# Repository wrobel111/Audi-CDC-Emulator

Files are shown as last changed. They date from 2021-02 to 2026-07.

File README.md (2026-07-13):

Audi CDC v1 1

# Audi CDC Emulator

Embedded CD changer emulator for Audi factory head units with Bluetooth audio streaming and hands-free phone functionality.

The project emulates an original Audi CD changer, allowing modern Bluetooth connectivity while preserving the original vehicle infotainment system. The hardware and firmware were designed to integrate seamlessly with factory radios without permanent vehicle modifications.

---

## Features

- Audi CD changer (CDC) protocol emulation
- Bluetooth audio streaming (A2DP)
- Hands-free phone functionality (HFP)
- Steering wheel (Rem-C line) and radio button support
- UART communication with Bluetooth module using AT commands
- Custom hardware designed for automotive applications
- AVR firmware written in C/C++

---

## Hardware

### Microcontroller

- ATmega328PB

### Bluetooth module

- BK3254

The Bluetooth module is controlled through UART using AT commands.

Supported AT commands:
https://github.com/tomaskovacik/BK3254/wiki/Supported-commands-and-event-send-from-module

---

## Hardware Design

The PCB was designed specifically for integration with the Audi factory audio system.

Main hardware components include:

- ATmega328PB microcontroller
- BK3254 Bluetooth module
- Audio amplifier
- Automotive power supply interface
- ISP programming connector
- UART service connector

Hardware design files are available in the `Hardware` directory.

---

## Firmware

The firmware is responsible for:

- emulating the Audi CD changer
- controlling the Bluetooth module
- handling button events
- switching between music playback and phone calls
- managing amplifier enable signals
- communication with the factory head unit

- ## Development History

### 24 May 2025

#### Added

- Support for BK3254 Bluetooth module
- Bluetooth music streaming
- Hands-free phone functionality

#### Changed

- Migrated timer implementation from Timer0 to Timer3 on ATmega328PB

---

## PCB Revision Notes (v1.1)

The following improvements are planned for the next PCB revision:

1. Add AUX detection using the switching contacts of the 3.5 mm jack connector.
2. Standardize the design to use the BK3254 Bluetooth module only.
3. Verify amplifier enable signal timing.
4. Replace the programming connector with a standard 6-pin ISP header.
5. Reorder the serial connector pinout:

   - +5 V
   - TX
   - RX
   - GND

6. Replace the audio amplifier with the SSM2211.
   - The SSM2211 uses an active LOW enable input, requiring inverted control logic.
7. Add series resistors and TVS protection diodes on the USB data lines.
8. Improve Digispark module pin placement for easier assembly and debugging.

CDC v1 1 with inprovements

---

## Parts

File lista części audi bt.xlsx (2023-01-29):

Zamówione | Part | Value | Device | Package | Library | Cena |  | Gdzie
100 szt. | C1 | 100n | C-EUC0805 | C0805 | rcl | 0,08050 |  | https://www.tme.eu/pl/details/cl21b104kbcnnnc/kondensatory-mlcc-smd-0805/samsung/
100 szt. | C2 | 22p | C-EUC0805 | C0805 | rcl | 0.06296 |  | https://www.tme.eu/pl/details/cc0805jrnpo9220/kondensatory-mlcc-smd-0805/yageo/cc0805jrnpo9bn220/
 | C3 | 22p | C-EUC0806 | C0806 | rcl | 0.06297
 | C4 | 100n | C-EUC0805 | C0805 | rcl | 0,08050
 | C5 | 100n | C-EUC0805 | C0805 | rcl | 0,08050
 | C6 | 100n | C-EUC0805 | C0805 | rcl | 0,08050
 | C7 | 100n | C-EUC0805 | C0805 | rcl | 0,08050
 | C8 | 100n | C-EUC0805 | C0805 | rcl | 0,08050
 | C9 | 100n | C-EUC0805 | C0805 | rcl | 0,08050
100 szt. | C10 | 1u | C-EUC0805 | C0805 | rcl | 0.100 |  | https://allegro.pl/oferta/kondensator-smd-0805-1uf-25v-10-szt-1337-10-6880076309
 | C11 | 1u | C-EUC0805 | C0805 | rcl | 0.100
 | C12 | 1u | C-EUC0805 | C0805 | rcl | 0.100
 | C13 | 1u | C-EUC0805 | C0805 | rcl | 0.100
 | C14 | 1u | C-EUC0805 | C0805 | rcl | 0.100
 | C15 | 1u | C-EUC0805 | C0805 | rcl | 0.100
 | C16 | 1u | C-EUC0805 | C0805 | rcl | 0.100
 | C17 | 1u | C-EUC0805 | C0805 | rcl | 0.100
 | C18 | 1u | C-EUC0805 | C0805 | rcl | 0.100
 | C19 | 1u | C-EUC0805 | C0805 | rcl | 0.100
 | C20 | 1u | C-EUC0805 | C0805 | rcl | 0.100
 | C21 | 100n | C-EUC0805 | C0805 | rcl | 0,08050
 | C22 | 100n | C-EUC0805 | C0805 | rcl | 0,08050
 | C23 | 1u | C-EUC0805 | C0805 | rcl | 0.100
 | C24 | 1u | C-EUC0805 | C0805 | rcl | 0.100
3 szt. | F1 | 1A | PTCFUSE-1206 | R1206 | adafruit | 2.06876 |  | https://www.tme.eu/pl/details/erbrg1r00v/bezpieczniki-smd-1206-szybkie/panasonic/
3 szt. | Q1 | 16 MHz | CRYSTALHC49S | HC49/S | crystal | 2,2983 |  | https://www.tme.eu/pl/details/16.00m-hc49-s/rezonatory-kwarcowe-tht/yic/
100 szt. | Q2 | BC847 | BC847ALT1SMD | SOT23 | transistor-npn | 0.029 |  | https://pl.aliexpress.com/item/33011051664.html?spm=a2g0s.9042311.0.0.27425c0fiXW19s
100 szt. | R1 | 10k | R-EU_R0805 | R0805 | rcl | 0.035 |  | https://pl.aliexpress.com/item/32969301387.html?spm=a2g0s.9042311.0.0.27425c0fiXW19s
100 szt. | R2 | 12k | R-EU_R0805 | R0805 | rcl | 0,06133 |  | https://www.tme.eu/pl/details/smd0805-12k-1%25/rezystory-smd-0805/royal-ohm/0805s8f1202t5e/
 | R3 | 12k | R-EU_R0805 | R0805 | rcl | 0,06133
 | R4 | 12k | R-EU_R0805 | R0805 | rcl | 0,06133
 | R5 | 12k | R-EU_R0805 | R0805 | rcl | 0,06133
 | R6 | 12k | R-EU_R0805 | R0805 | rcl | 0,06133
 | R7 | 12k | R-EU_R0805 | R0805 | rcl | 0,06133
 | R8 | 10k | R-EU_R0805 | R0805 | rcl | 0.035
 | R9 | 10k | R-EU_R0805 | R0805 | rcl | 0.035
 | R10 | 10k | R-EU_R0805 | R0805 | rcl | 0.035
 | R11 | 10k | R-EU_R0805 | R0805 | rcl | 0.035
 | R12 | 10k | R-EU_R0805 | R0805 | rcl | 0.035
100 szt. | R13 | 20k | R-EU_R0805 | R0805 | rcl | 0.06133 |  | https://www.tme.eu/pl/details/smd0805-20k-1%25/rezystory-smd-0805/royal-ohm/0805s8f2002t5e/
 | R14 | 20k | R-EU_R0805 | R0805 | rcl | 0.06133
100 szt. | R15 | 1,2k | R-EU_R0805 | R0805 | rcl | 0,06133 |  | https://www.tme.eu/pl/details/smd0805-1k2-1%25/rezystory-smd-0805/royal-ohm/0805s8f1201t5e/
 | R16 | 1,2k | R-EU_R0805 | R0805 | rcl | 0,06133
100 szt. | R17 | 0 | R-EU_R0805 | R0805 | rcl | 0.0213 |  | https://pl.aliexpress.com/item/32969301387.html?spm=a2g0s.9042311.0.0.27425c0fiXW19s
50 szt. | RESET |  | SWITCH_PUSHBUTTONSOFTTOUCHSMD_SJ | PUSHBUTTON_SMD_SJ | adafruit | 0.034 |  | https://pl.aliexpress.com/item/32652031692.html?spm=a2g0s.9042311.0.0.27425c0fEeSRBw
nie trzeba | S1 |  | pad do zlutowania
 | S2 |  | pad do zlutowania
 | S3 |  | pad do zlutowania
 | TP1 | TPB1,27 | TPB1,27 | B1,27 | testpad
 | TP2 | TPB1,27 | TPB1,27 | B1,27 | testpad
 | TP3 | TPB1,27 | TPB1,27 | B1,27 | testpad
 | TP4 | TPB1,27 | TPB1,27 | B1,27 | testpad
 | TP5 | TPB1,27 | TPB1,27 | B1,27 | testpad
 | TP6 | TPB1,27 | TPB1,27 | B1,27 | testpad
 | TP7 | TPB1,27 | TPB1,27 | B1,27 | testpad
 | TP8 | TPB1,27 | TPB1,27 | B1,27 | testpad
 | TP9 | TPB1,27 | TPB1,27 | B1,27 | testpad
10 szt. | TR1 | AUDIO_R | AUDIO_ISOLATION_TRANSFORMER_EI14 | EI14 | trafo EI14 | 1.150 |  | https://pl.aliexpress.com/item/32827431499.html?spm=a2g0s.9042311.0.0.50735c0friSdsd
 | TR2 | AUDIO_L | AUDIO_ISOLATION_TRANSFORMER_EI14 | EI14 | trafo EI14 | 1.150
 | TR3 | AUDIO_MIC | AUDIO_ISOLATION_TRANSFORMER_EI14 | EI14 | trafo EI14 | 1.150
2 szt. | U$7 | DIGISPARK | DIGISPARK | DIGISPARK | digispark | 5.720 |  | https://pl.aliexpress.com/item/32891293434.html
bk3254 3 szt. | U1 | BK3266_BOARD | BK3254 | 40PIN_BOARD | BK3266/BK3254 | 8.690 | Przesyłka | https://pl.aliexpress.com/item/32824037848.html
3 szt. | U2 | MEGA328P | MEGA8-AI | TQFP32-08 | atmel | 9.960 |  | https://www.tme.eu/pl/details/atmega328p-au/rodzina-avr-8-bit/microchip-atmel/
10 szt. | U3 | HT6872 | HT6872 | SO8 | HT6872 | 1.515 | przesylka | https://pl.aliexpress.com/item/32965069882.html?spm=a2g0s.9042311.0.0.27425c0fEeSRBw
 | U4 | HT6872 | HT6872 | SO8 | HT6872 | 2.515 | przesylka
 | U5 | HT6872 | HT6872 | SO8 | HT6872 | 3.515 | przesylka
10 szt. | U6 | AMS1117-3.3 | LM1117MPX-3.3 | SOT223 | lm1117 | 0.135 |  | https://pl.aliexpress.com/item/32834083645.html?spm=a2g0s.9042311.0.0.27425c0fEeSRBw
6 szt. | X1 | molex 4 pin | HEADER_POS4_43045-0401 | 43045-0400 | con-molex-micro-fit-3_0 | 2.000 |  | https://www.tme.eu/pl/details/mx-43045-0400/zlacza-sygnalowe-raster-3-00mm/molex/43045-0400/ | https://pl.aliexpress.com/item/32796641499.html
6 szt. | X2 | molex 16 pin | HEADER_POS16_43045-1600 | 43045-1600 | con-molex-micro-fit-3_0 | 3.260 |  | https://www.tme.eu/pl/details/mx-43045-1600/zlacza-sygnalowe-raster-3-00mm/molex/43045-1600/ | https://pl.aliexpress.com/item/4000786382682.html
 | X3 | goldpin 4 pin | PINHD-1X4 | 1X04 | pinhead
10 szt. | X4 | mini STEREOJACK | STEREOJACK | STX3100 | audio amplifier example | 0.232 |  | https://pl.aliexpress.com/item/33030284477.html?spm=a2g0s.9042311.0.0.27425c0fEeSRBw
10 szt. | X5 | USB-A-H | USB-A-H | USB-A-H | con-usb | 0.286 |  | https://pl.aliexpress.com/item/1005001705110068.html?spm=a2g0s.9042311.0.0.27425c0fEeSRBw
2 szt. |  | z97 | obudowa |  |  | 6.090 |  | https://www.tme.eu/pl/details/z-97/obudowy-z-panelem/kradex/z97/
5 szt. |  |  | pcb |  | 5,7 $ | 4.200 |  | jlcpcb
 |  |  |  |  | Suma | 55.479
 |  |  | mini iso niebieskie

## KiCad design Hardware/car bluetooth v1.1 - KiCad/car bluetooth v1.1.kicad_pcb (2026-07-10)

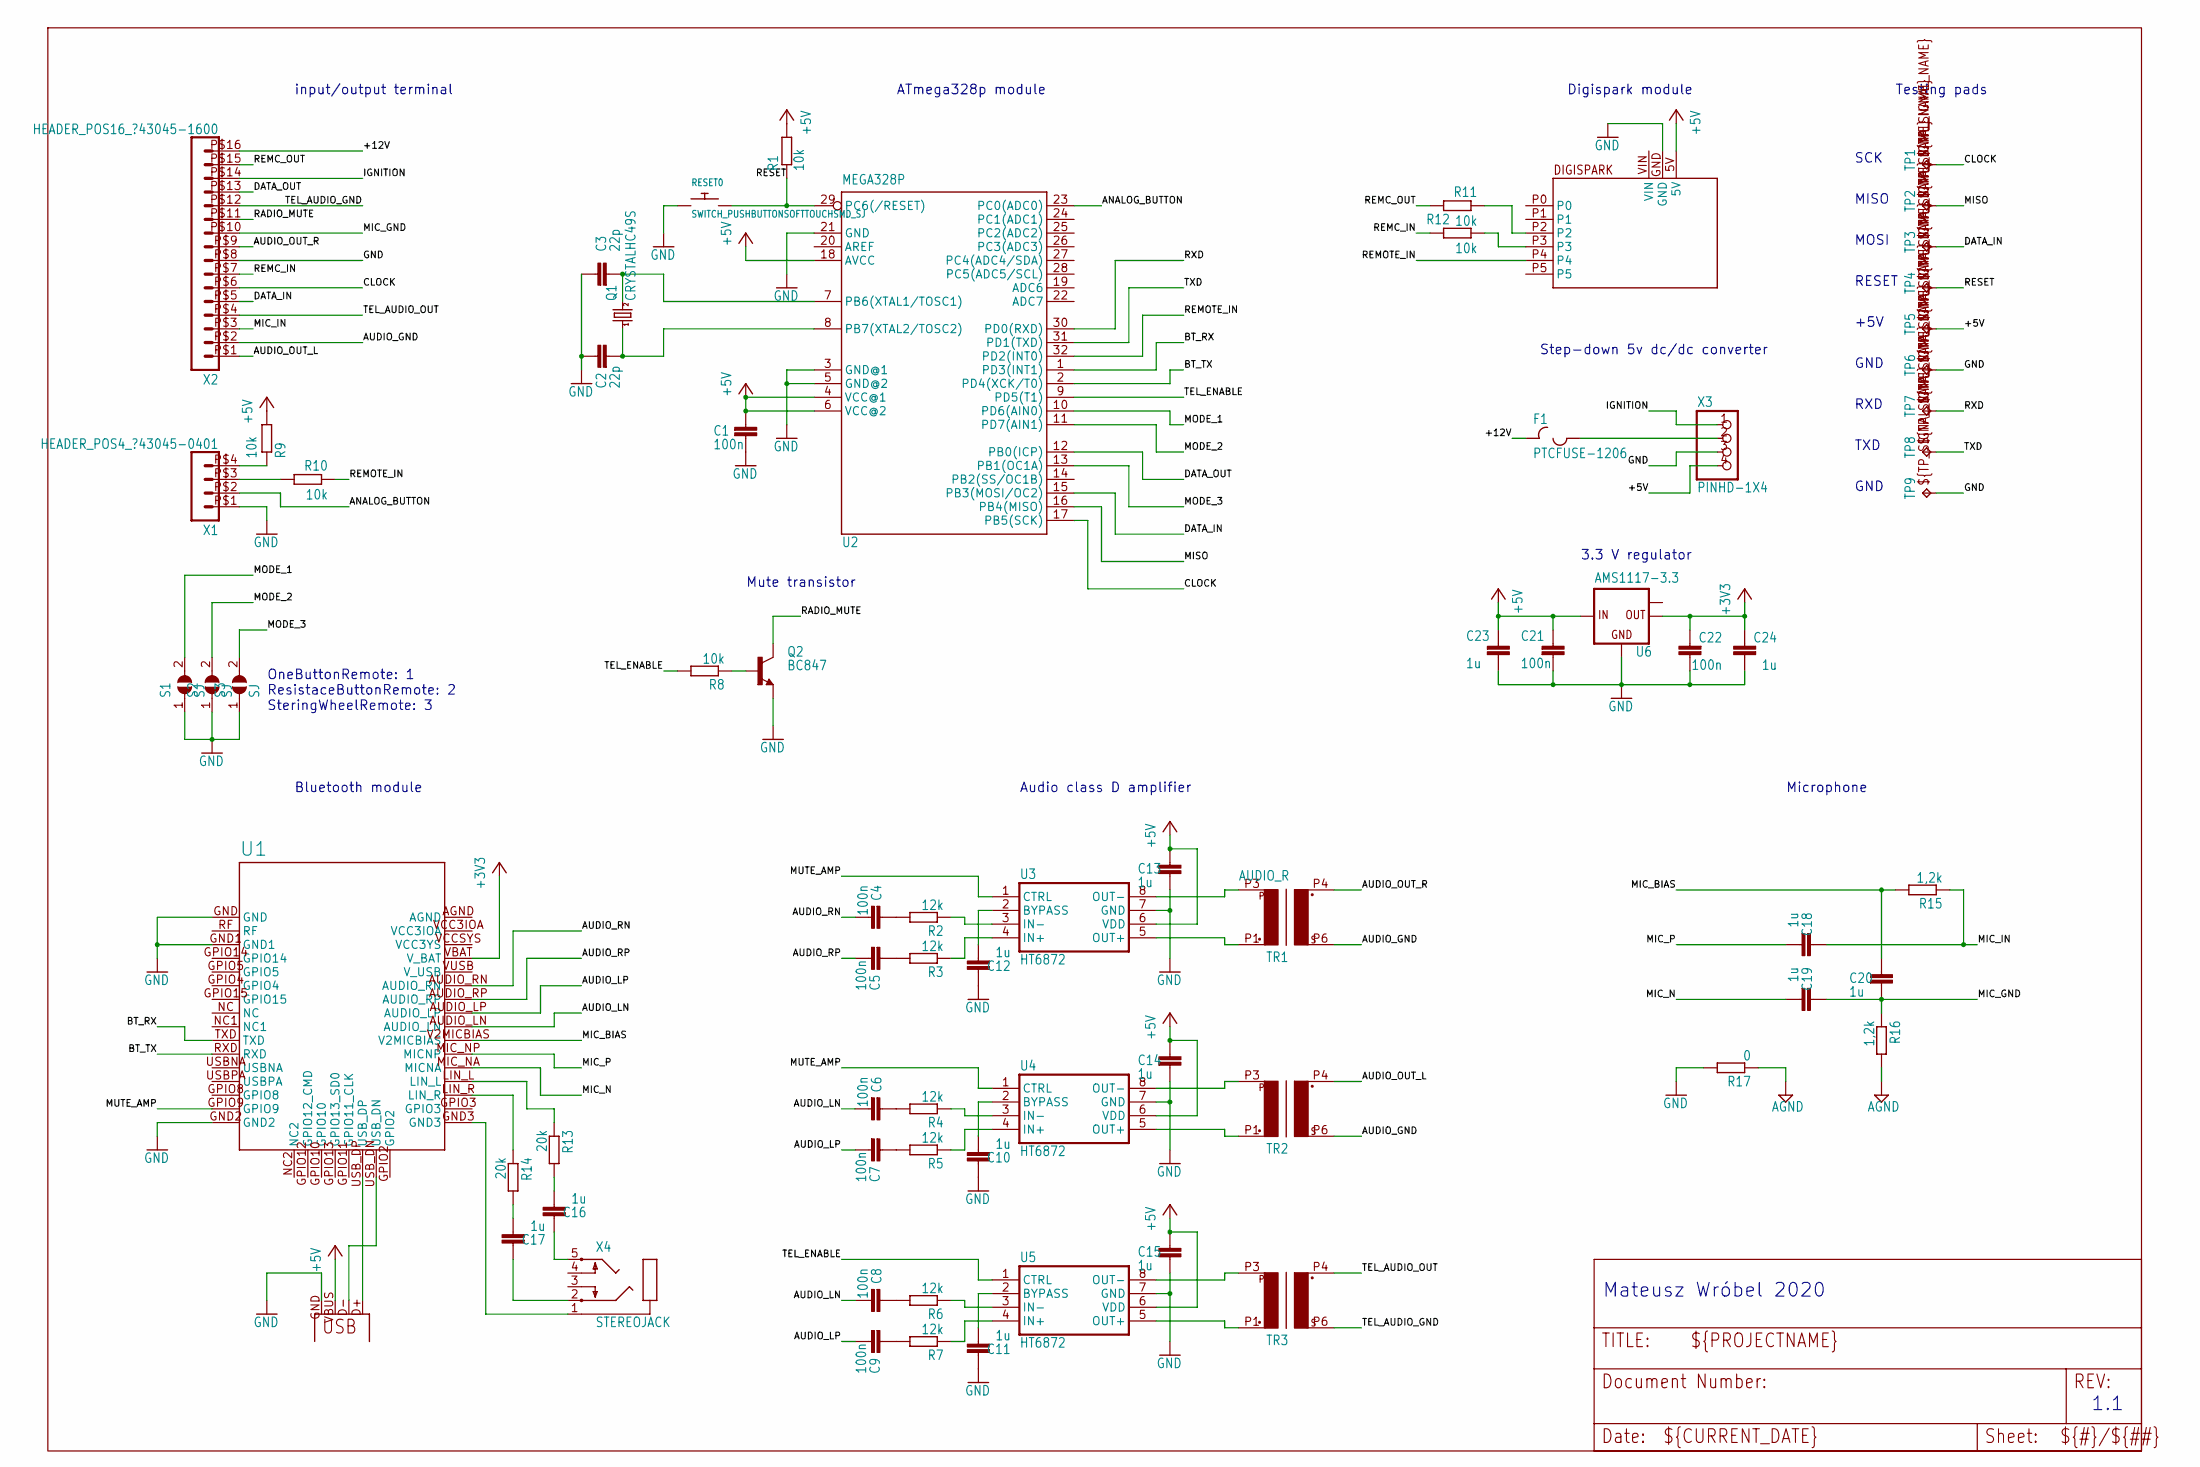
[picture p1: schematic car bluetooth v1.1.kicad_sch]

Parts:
C1, C4, C5, C6, C7, C8, C9, C21, C22: 100n; C0805
C2, C3: 22p; C0805
C10, C11, C12, C13, C14, C15, C16, C17, C18, C19, C20, C23, C24: 1u; C0805
F1: PTCFUSE-1206; R1206
Q1: CRYSTALHC49S; HC49_S
Q2: BC847; SOT23
R1, R8, R9, R10, R11, R12: 10k; R0805
R2, R3, R4, R5, R6, R7: 12k; R0805
R13, R14: 20k; R0805
R15, R16: 1,2k; R0805
R17: 0; R0805
RESET0: SWITCH_PUSHBUTTONSOFTTOUCHSMD_SJ; PUSHBUTTON_SMD_SJ
S1, S2, S3: SJ
TP1, TP2, TP3, TP4, TP5, TP6, TP7, TP8, TP9: TPB1,27; B1,27
TR1: AUDIO_R; EI14
TR2: AUDIO_L; EI14
TR3: AUDIO_MIC; EI14
U1: BK3266_BOARD; 40PIN_BOARD
U2: MEGA328P; TQFP32-08
U3, U4, U5: HT6872; SO8
U6: AMS1117-3.3; SOT223
U$7: DIGISPARK
X1: HEADER_POS4_?43045-0401; 43045-0400
X2: HEADER_POS16_?43045-1600; 43045-1600
X3: PINHD-1X4; 1X04
X4: STEREOJACK; STX3100
X5: USB-A-H

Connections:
+3V3: C22.2, C24.2, U1.VBAT (V_BAT), U6.2 (OUT)
+5V: C1.1, C13.1, C14.1, C15.1, C21.1, C23.1, R1.2, R9.1, TP5.TP, U2.4 (VCC@1), U2.6 (VCC@2), U2.18 (AVCC), U3.6 (VDD), U4.6 (VDD), U5.6 (VDD), U6.3 (IN), U$7.5V, X3.4, X5.VBUS
+12V: F1.1, X2.P$16 (16)
AGND: R16.2, R17.1
ANALOG_BUTTON: U2.23 (PC0(ADC0)), X1.P$2 (2)
AUDIO_GND: TR1.P6 (P4), TR2.P6 (P4), X2.P$2 (2)
AUDIO_LN: C6.2, C8.2, U1.AUDIO_LN
AUDIO_LP: C7.2, C9.2, U1.AUDIO_LP
AUDIO_OUT_L: TR2.P4 (P3), X2.P$1 (1)
AUDIO_OUT_R: TR1.P4 (P3), X2.P$9 (9)
AUDIO_RN: C4.2, U1.AUDIO_RN
AUDIO_RP: C5.2, U1.AUDIO_RP
BT_RX: U1.TXD, U2.1 (PD3(INT1))
BT_TX: U1.RXD, U2.2 (PD4(XCK/T0))
CLOCK: TP1.TP, U2.17 (PB5(SCK)), X2.P$6 (6)
DATA_IN: TP3.TP, U2.15 (PB3(MOSI/OC2)), X2.P$5 (5)
DATA_OUT: U2.12 (PB0(ICP)), X2.P$13 (13)
GND: C1.2, C2.1, C3.1, C10.1, C11.1, C12.1, C13.2, C14.2, C15.2, C21.2, C22.1, C23.2, C24.1, Q2.2 (E), R17.2, RESET0.P$1, S1.1, S2.1, S3.1, TP6.TP, TP9.TP, U1.GND, U1.GND1, U1.GND2, U2.3 (GND@1), U2.5 (GND@2), U2.21 (GND), U3.7 (GND), U4.7 (GND), U5.7 (GND), U6.1 (GND), U$7.GND, X1.P$1 (1), X2.P$8 (8), X3.3, X5.GND
IGNITION: X2.P$14 (14), X3.1
MIC_BIAS: C20.1, R15.2, U1.V2MICBIAS
MIC_GND: C19.1, C20.2, R16.1, X2.P$10 (10)
MIC_IN: C18.1, R15.1, X2.P$3 (3)
MIC_N: C19.2, U1.MIC_NA (MICNA)
MIC_P: C18.2, U1.MIC_NP (MICNP)
MISO: TP2.TP, U2.16 (PB4(MISO))
MODE_1: S1.2, U2.10 (PD6(AIN0))
MODE_2: S2.2, U2.11 (PD7(AIN1))
MODE_3: S3.2, U2.13 (PB1(OC1A))
MUTE_AMP: U1.GPIO9, U3.1 (CTRL), U4.1 (CTRL)
unnamed: R14.1, U1.LIN_R
unnamed: C3.2, Q1.2, U2.7 (PB6(XTAL1/TOSC1))
unnamed: C2.2, Q1.1, U2.8 (PB7(XTAL2/TOSC2))
unnamed: Q2.1 (B), R8.1
unnamed: TR2.P3 (P2), U4.8 (OUT-)
unnamed: TR2.P1, U4.5 (OUT+)
unnamed: TR3.P3 (P2), U5.8 (OUT-)
unnamed: TR3.P1, U5.5 (OUT+)
unnamed: TR1.P1, U3.5 (OUT+)
unnamed: R2.1, U3.3 (IN-)
unnamed: R3.1, U3.4 (IN+)
unnamed: R4.1, U4.3 (IN-)
unnamed: R5.1, U4.4 (IN+)
unnamed: R6.1, U5.3 (IN-)
unnamed: R7.1, U5.4 (IN+)
unnamed: C5.1, R3.2
unnamed: C4.1, R2.2
unnamed: C6.1, R4.2
unnamed: C7.1, R5.2
unnamed: C8.1, R6.2
unnamed: C9.1, R7.2
unnamed: R9.2, X1.P$4 (4)
unnamed: R10.1, X1.P$3 (3)
unnamed: R12.2, U$7.P3
unnamed: R11.2, U$7.P2
unnamed: F1.2, X3.2
unnamed: U1.USB_DP, X5.D+
unnamed: C12.2, U3.2 (BYPASS)
unnamed: C10.2, U4.2 (BYPASS)
unnamed: C11.2, U5.2 (BYPASS)
unnamed: U1.USB_DN, X5.D-
unnamed: R13.1, U1.LIN_L
unnamed: TR1.P3 (P2), U3.8 (OUT-)
unnamed: C17.1, X4.2
unnamed: C16.1, X4.5
unnamed: C17.2, R14.2
unnamed: C16.2, R13.2
unnamed: U1.GND3, X4.1
RADIO_MUTE: Q2.3 (C), X2.P$11 (11)
REMC_IN: R12.1, X2.P$7 (7)
REMC_OUT: R11.1, X2.P$15 (15)
REMOTE_IN: R10.2, U2.32 (PD2(INT0)), U$7.P4
RESET: R1.1, RESET0.P$2, TP4.TP, U2.29 (PC6(/RESET))
RXD: TP7.TP, U2.30 (PD0(RXD))
TEL_AUDIO_GND: TR3.P6 (P4), X2.P$12 (12)
TEL_AUDIO_OUT: TR3.P4 (P3), X2.P$4 (4)
TEL_ENABLE: R8.2, U2.9 (PD5(T1)), U5.1 (CTRL)
TXD: TP8.TP, U2.31 (PD1(TXD))

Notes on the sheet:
GND
OneButtonRemote: 1 ResistaceButtonRemote: 2 SteringWheelRemote: 3
Step-down 5v dc/dc converter
Testing pads
RESET
1.1
RXD
3.3 V regulator
Mute transistor
TXD
MISO
MOSI
Microphone
Audio class D amplifier
input/output terminal
+5V
Bluetooth module
ATmega328p module
Digispark module
Mateusz Wróbel 2020
SCK

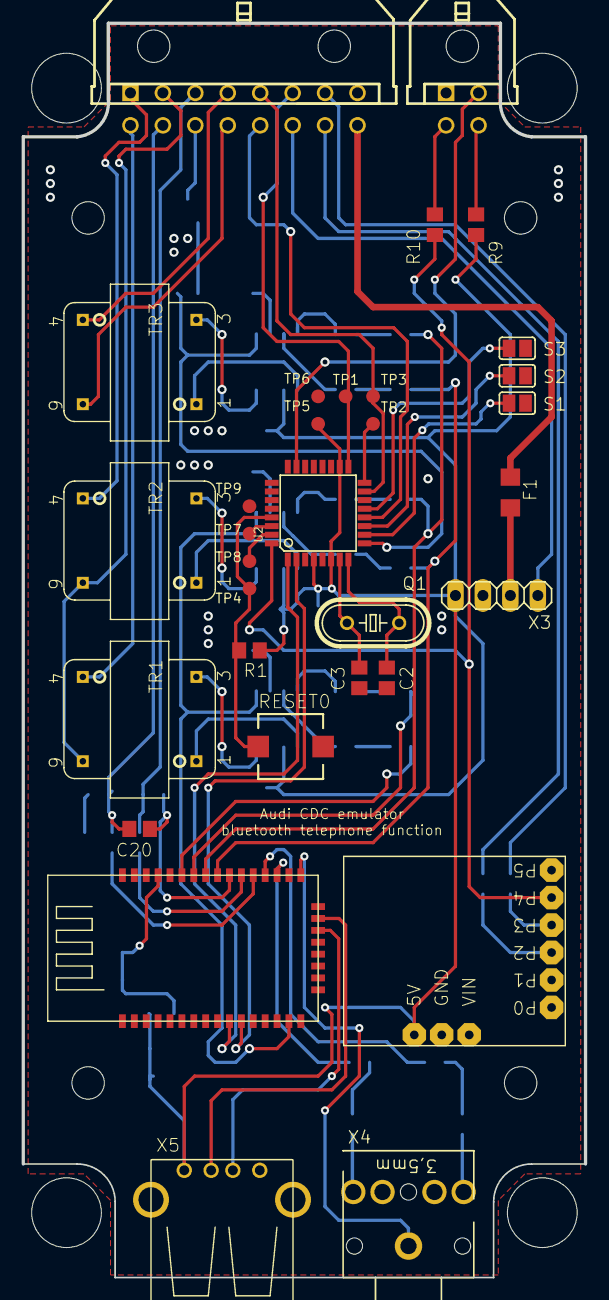
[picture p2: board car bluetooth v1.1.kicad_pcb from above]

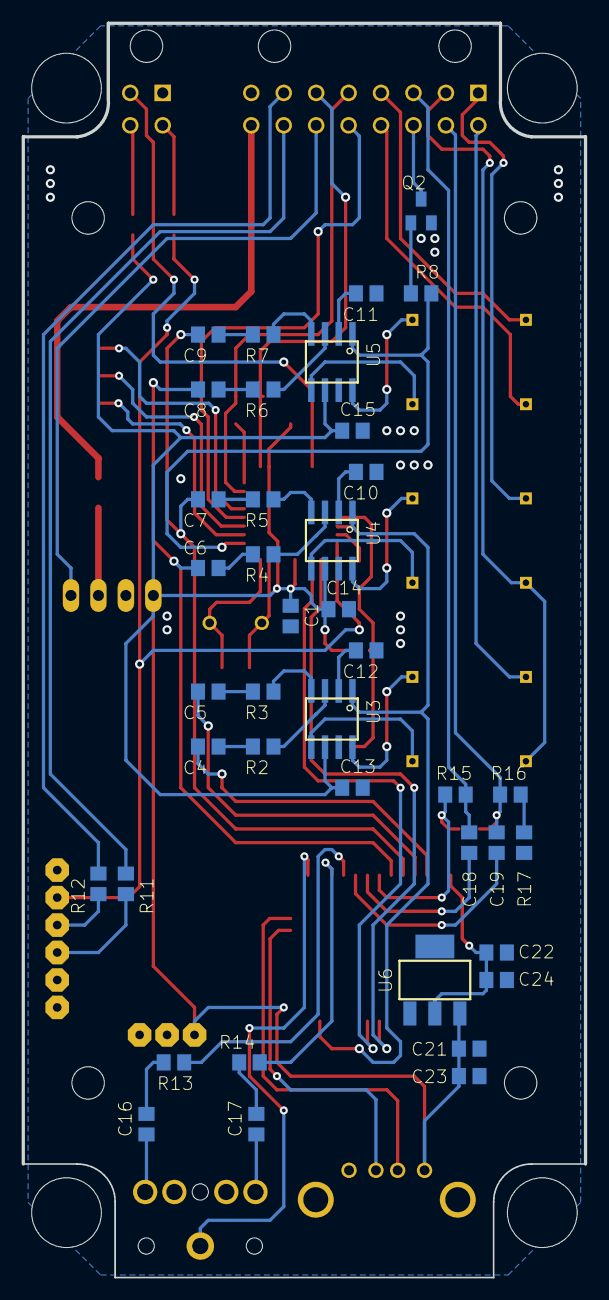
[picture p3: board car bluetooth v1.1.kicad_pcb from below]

Board: 16 copper layers, 52.0 x 116.0 mm, 80 parts (40 on the bottom side), 77 nets.

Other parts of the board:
UNK_HOLE_0: dummyfp0
UNK_HOLE_1: dummyfp1
UNK_HOLE_2: dummyfp2
UNK_HOLE_3: dummyfp3
UNK_HOLE_4: dummyfp4
UNK_HOLE_5: dummyfp5
UNK_HOLE_6: dummyfp6
UNK_HOLE_7: dummyfp7

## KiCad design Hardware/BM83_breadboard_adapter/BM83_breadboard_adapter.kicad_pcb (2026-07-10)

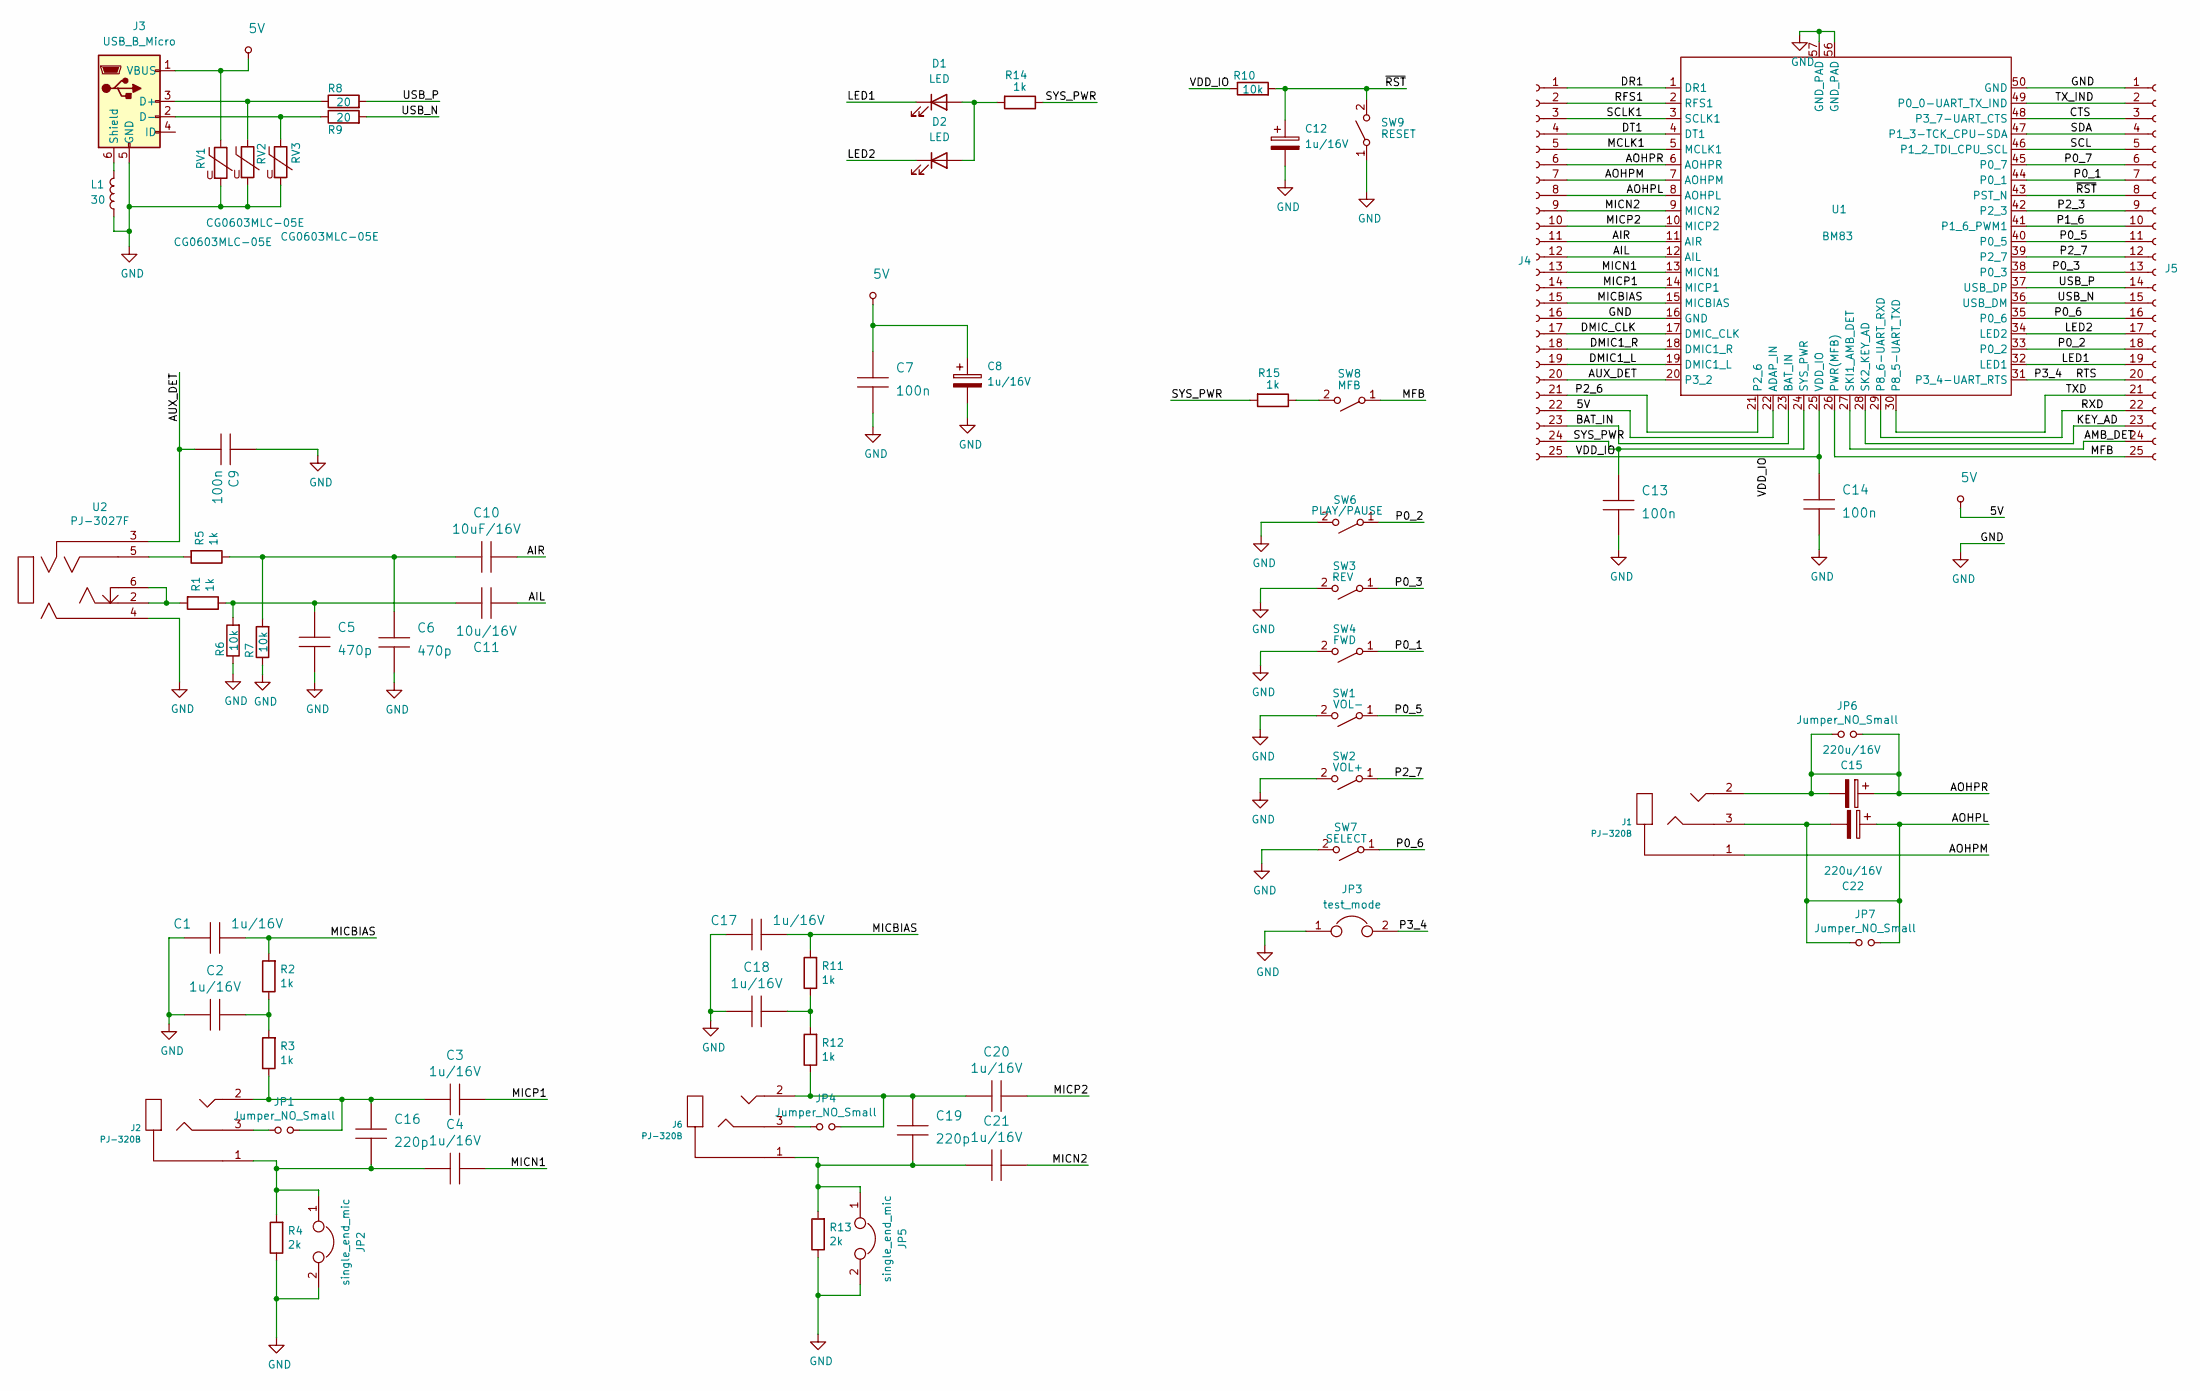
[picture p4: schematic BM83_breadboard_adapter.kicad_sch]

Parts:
C1, C2, C3, C4, C17, C18, C20, C21: 1u/16V; C_1206_HandSoldering
C5, C6: 470p; C_0805_HandSoldering
C7, C9, C13, C14: 100n; C_0805_HandSoldering
C8, C12: 1u/16V; TantalC_SizeA_EIA-3216_HandSoldering
C10: 10uF/16V; C_1206_HandSoldering
C11: 10u/16V; C_1206_HandSoldering
C15, C22: 220u/16V; C_Radial_D6.3_L11.2_P2.5
C16, C19: 220p; C_0805_HandSoldering
D1, D2: LED; LED_1206_HandSoldering
J1, J2, J6: PJ-320B; 3.5mm_stereo_jack_PJ320B
J3: USB_B_Micro; USB_Micro-B
J4, J5: Conn_01x25_Female; Pin_Header_Straight_1x25
JP1, JP4, JP6, JP7: Jumper_NO_Small; SolderJumper-2_P1.3mm_Open_RoundedPad1.0x1.5mm
JP2, JP5: single_end_mic; SolderJumper-2_P1.3mm_Open_RoundedPad1.0x1.5mm
JP3: test_mode; Pin_Header_Straight_1x02
L1: 30; R_1206_HandSoldering
R1, R2, R3, R5, R11, R12, R14, R15: 1k; R_0805_HandSoldering
R4, R13: 2k; R_0805_HandSoldering
R6, R7, R10: 10k; R_0805_HandSoldering
R8, R9: 20; R_0805_HandSoldering
RV1, RV2, RV3: CG0603MLC-05E; R_0603_HandSoldering
SW1: VOL-; SW_SPST_FSMSM
SW2: VOL+; SW_SPST_FSMSM
SW3: REV; SW_SPST_FSMSM
SW4: FWD; SW_SPST_FSMSM
SW6: PLAY/PAUSE; SW_SPST_FSMSM
SW7: SELECT; SW_SPST_FSMSM
SW8: MFB; SW_SPST_FSMSM
SW9: RESET; SW_SPST_FSMSM
U1: BM83
U2: PJ-3027F; PJ-327A

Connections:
5V: C7.1, C8.1, J3.1 (VBUS), J4.22, RV1.1, U1.22 (ADAP_IN)
/AIL: C11.2, J4.12, U1.12 (AIL)
/AIR: C10.1, J4.11, U1.11 (AIR)
/AMB_DET: J5.24, U1.27 (SKI1_AMB_DET)
/AOHPL: C22.1, C22.2, J1.3, J4.8, JP7.1, JP7.2, U1.8 (AOHPL)
/AOHPM: J1.1, J4.7, U1.7 (AOHPM)
/AOHPR: C15.1, C15.2, J1.2, J4.6, JP6.1, JP6.2, U1.6 (AOHPR)
/AUX_DET: C9.2, J4.20, U1.20 (P3_2), U2.3
/BAT_IN: J4.23, U1.23 (BAT_IN)
/CTS: J5.3, U1.48 (P3_7-UART_CTS)
/DMIC1_L: J4.19, U1.19 (DMIC1_L)
/DMIC1_R: J4.18, U1.18 (DMIC1_R)
/DMIC_CLK: J4.17, U1.17 (DMIC_CLK)
/DR1: J4.1, U1.1 (DR1)
/DT1: J4.4, U1.4 (DT1)
/KEY_AD: J5.23, U1.28 (SK2_KEY_AD)
/LED1: D1.1 (K), J5.19, U1.32 (LED1)
/LED2: D2.1 (K), J5.17, U1.34 (LED2)
/MCLK1: J4.5, U1.5 (MCLK1)
/MFB: J5.25, SW8.1 (A), U1.26 (PWR(MFB))
/MICBIAS: C1.1, C17.1, J4.15, R2.2, R11.2, U1.15 (MICBIAS)
/MICN1: C4.1, J4.13, U1.13 (MICN1)
/MICN2: C21.1, J4.9, U1.9 (MICN2)
/MICP1: C3.1, J4.14, U1.14 (MICP1)
/MICP2: C20.1, J4.10, U1.10 (MICP2)
/P0_1: J5.7, SW4.1 (A), U1.44 (P0_1)
/P0_2: J5.18, SW6.1 (A), U1.33 (P0_2)
/P0_3: J5.13, SW3.1 (A), U1.38 (P0_3)
/P0_5: J5.11, SW1.1 (A), U1.40 (P0_5)
/P0_6: J5.16, SW7.1 (A), U1.35 (P0_6)
/P0_7: J5.6, U1.45 (P0_7)
/P1_6: J5.10, U1.41 (P1_6_PWM1)
/P2_3: J5.9, U1.42 (P2_3)
/P2_6: J4.21, U1.21 (P2_6)
/P2_7: J5.12, SW2.1 (A), U1.39 (P2_7)
/P3_4: J5.20, JP3.2, U1.31 (P3_4-UART_RTS)
/RFS1: J4.2, U1.2 (RFS1)
/RXD: J5.22, U1.29 (P8_6-UART_RXD)
/SCL: J5.5, U1.46 (P1_2_TDI_CPU_SCL)
/SCLK1: J4.3, U1.3 (SCLK1)
/SDA: J5.4, U1.47 (P1_3-TCK_CPU-SDA)
/SYS_PWR: C13.1, J4.24, R14.1, R15.2, U1.24 (SYS_PWR)
/TXD: J5.21, U1.30 (P8_5-UART_TXD)
/TX_IND: J5.2, U1.49 (P0_0-UART_TX_IND)
/USB_N: J5.15, R9.2, U1.36 (USB_DM)
/USB_P: J5.14, R8.2, U1.37 (USB_DP)
/VDD_IO: C14.1, J4.25, R10.1, U1.25 (VDD_IO)
/~RST: C12.1, J5.8, R10.2, SW9.2 (B), U1.43 (PST_N)
GND: C1.2, C2.2, C5.2, C6.2, C7.2, C8.2, C9.1, C12.2, C13.2, C14.2, C17.2, C18.2, J3.5 (GND), J4.16, J5.1, JP2.2, JP3.1, JP5.2, L1.1, R4.1, R6.1, R7.1, R13.1, RV1.2, RV2.2, RV3.2, SW1.2 (B), SW2.2 (B), SW3.2 (B), SW4.2 (B), SW6.2 (B), SW7.2 (B), SW9.1 (A), U1.16 (GND), U1.50 (GND), U1.56 (GND_PAD), U1.57 (GND_PAD), U2.4
unnamed: C2.1, R2.1, R3.2
unnamed: C6.1, C10.2, R5.1, R7.2
unnamed: C5.1, C11.1, R1.1, R6.2
unnamed: C3.2, C16.1, J2.2, JP1.2, R3.1
unnamed: C4.2, C16.2, J2.1, JP2.1, R4.2
unnamed: C18.1, R11.1, R12.2
unnamed: C19.1, C20.2, J6.2, JP4.2, R12.1
unnamed: C19.2, C21.2, J6.1, JP5.1, R13.2
unnamed: D1.2 (A), D2.2 (A), R14.2
unnamed: J2.3, JP1.1
unnamed: J3.2 (D-), R9.1, RV3.1
unnamed: J3.3 (D+), R8.1, RV2.1
unnamed: J3.6 (Shield), L1.2
unnamed: J6.3, JP4.1
unnamed: R1.2, U2.2, U2.6
unnamed: R5.2, U2.5
unnamed: R15.1, SW8.2 (B)

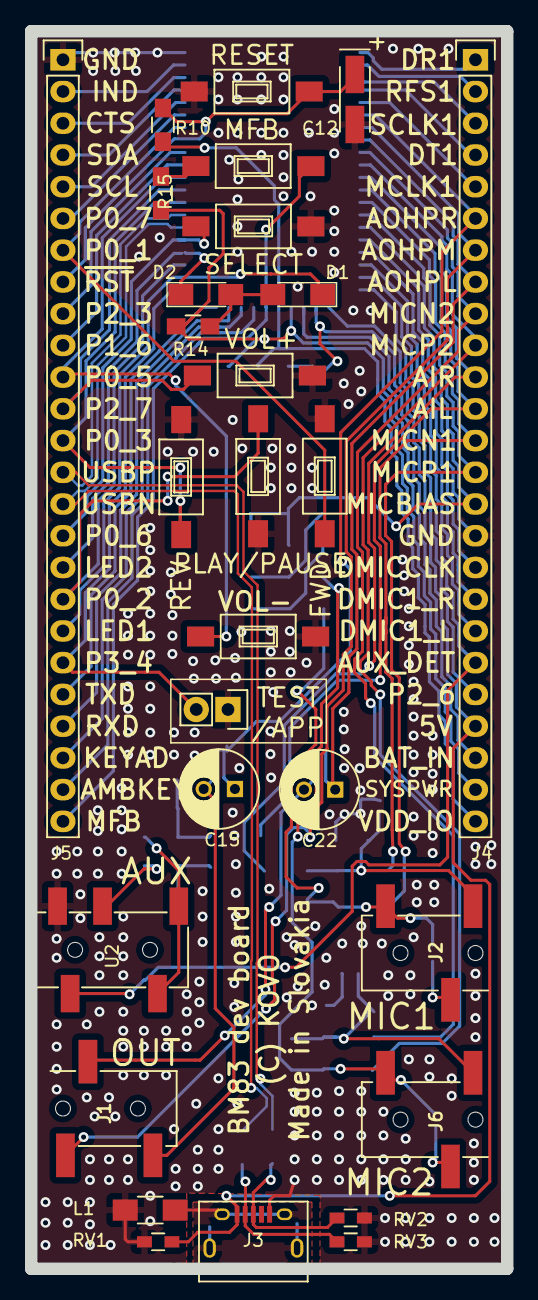
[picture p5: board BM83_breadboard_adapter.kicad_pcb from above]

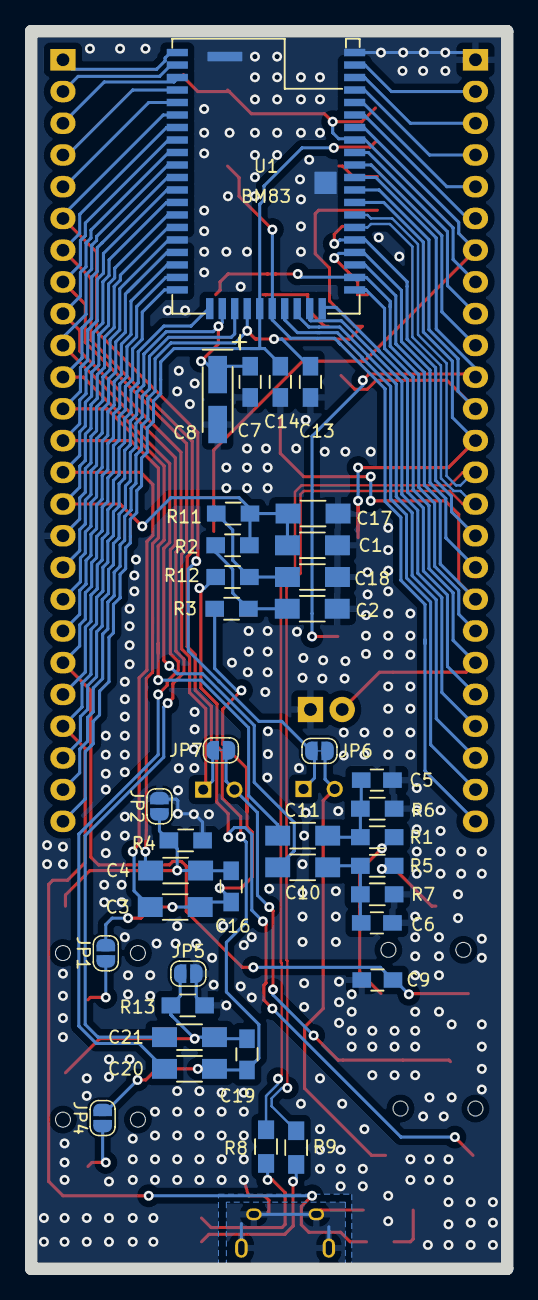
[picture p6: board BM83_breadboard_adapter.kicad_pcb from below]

Board: 2 copper layers, 38.1 x 99.1 mm, 66 parts (38 on the bottom side), 66 nets.

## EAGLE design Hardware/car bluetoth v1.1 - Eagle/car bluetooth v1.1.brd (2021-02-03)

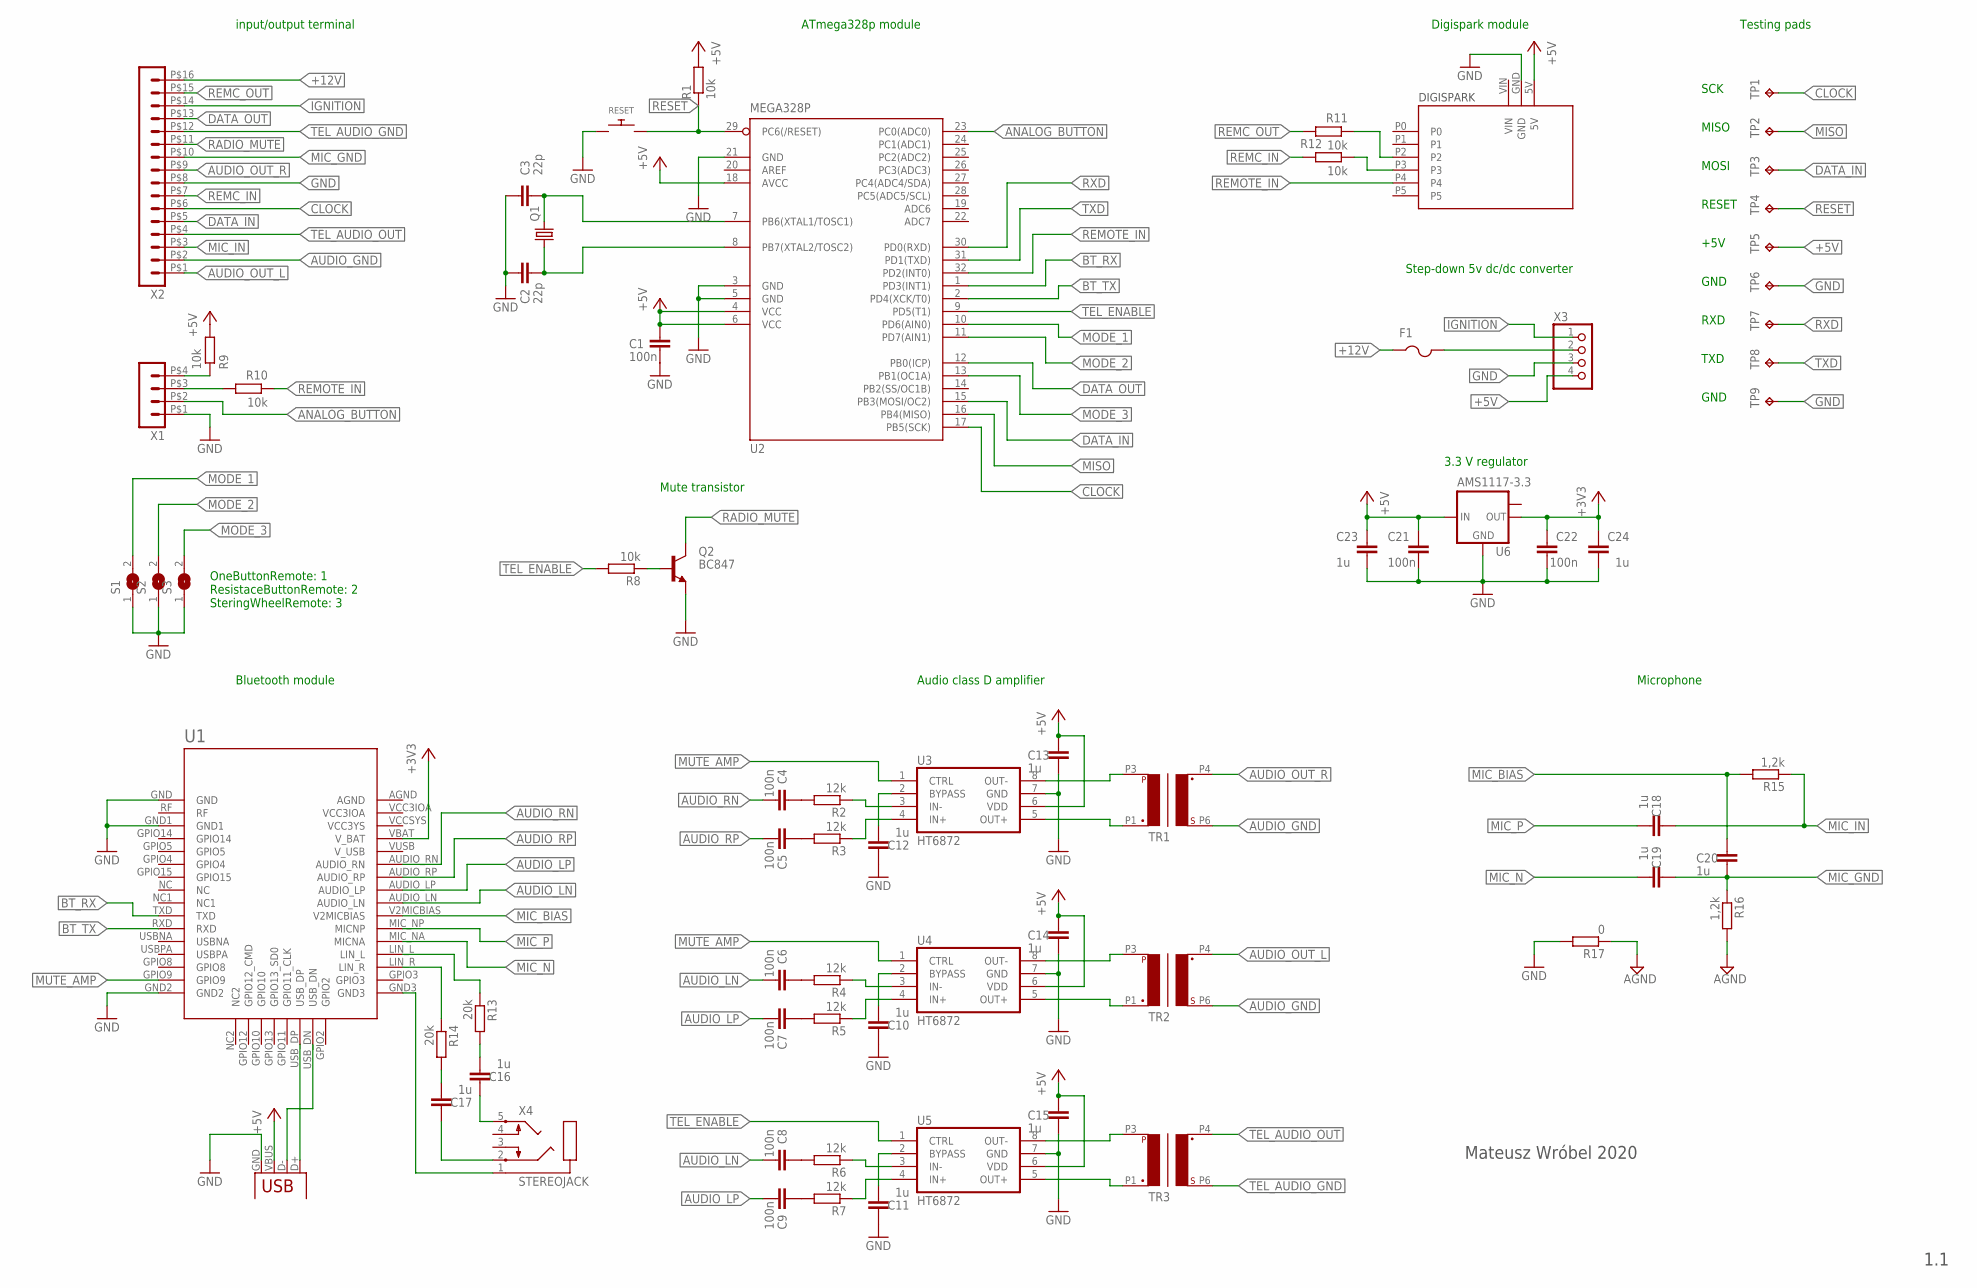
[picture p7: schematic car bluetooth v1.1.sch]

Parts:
C1, C4, C5, C6, C7, C8, C9, C21, C22: 100n; C0805
C2, C3: 22p; C0805
C10, C11, C12, C13, C14, C15, C16, C17, C18, C19, C20, C23, C24: 1u; C0805
F1: PTCFUSE-1206; R1206
Q1: CRYSTALHC49S; HC49/S
Q2: BC847; SOT23
R1, R8, R9, R10, R11, R12: 10k; R0805
R2, R3, R4, R5, R6, R7: 12k; R0805
R13, R14: 20k; R0805
R15, R16: 1,2k; R0805
R17: 0; R0805
RESET: SWITCH_PUSHBUTTONSOFTTOUCHSMD_SJ; PUSHBUTTON_SMD_SJ
S1, S2, S3: SJ
TP1, TP2, TP3, TP4, TP5, TP6, TP7, TP8, TP9: TPB1,27; B1,27
TR1: AUDIO_R; EI14
TR2: AUDIO_L; EI14
TR3: AUDIO_MIC; EI14
U1: BK3266_BOARD; 40PIN_BOARD
U2: MEGA328P; TQFP32-08
U3, U4, U5: HT6872; SO8
U6: AMS1117-3.3; SOT223
U$7: DIGISPARK
X1: HEADER_POS4_43045-0401; 43045-0400
X2: HEADER_POS16_43045-1600; 43045-1600
X3: PINHD-1X4; 1X04
X4: STEREOJACK; STX3100
X5: USB-A-H

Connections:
+3V3: C22.2, C24.2, U1.VBAT (V_BAT), U6.2 (OUT)
+5V: C1.1, C13.1, C14.1, C15.1, C21.1, C23.1, R1.2, R9.1, TP5.TP, U2.4 (VCC), U2.6 (VCC), U2.18 (AVCC), U3.6 (VDD), U4.6 (VDD), U5.6 (VDD), U6.3 (IN), U$7.5V, X3.4, X5.VBUS
+12V: F1.1, X2.P$16 (16)
AGND: R16.2, R17.1
ANALOG_BUTTON: U2.23 (PC0(ADC0)), X1.P$2 (2)
AUDIO_GND: TR1.P6 (P4), TR2.P6 (P4), X2.P$2 (2)
AUDIO_LN: C6.2, C8.2, U1.AUDIO_LN
AUDIO_LP: C7.2, C9.2, U1.AUDIO_LP
AUDIO_OUT_L: TR2.P4 (P3), X2.P$1 (1)
AUDIO_OUT_R: TR1.P4 (P3), X2.P$9 (9)
AUDIO_RN: C4.2, U1.AUDIO_RN
AUDIO_RP: C5.2, U1.AUDIO_RP
BT_RX: U1.TXD, U2.1 (PD3(INT1))
BT_TX: U1.RXD, U2.2 (PD4(XCK/T0))
CLOCK: TP1.TP, U2.17 (PB5(SCK)), X2.P$6 (6)
DATA_IN: TP3.TP, U2.15 (PB3(MOSI/OC2)), X2.P$5 (5)
DATA_OUT: U2.12 (PB0(ICP)), X2.P$13 (13)
GND: C1.2, C2.1, C3.1, C10.1, C11.1, C12.1, C13.2, C14.2, C15.2, C21.2, C22.1, C23.2, C24.1, Q2.2 (E), R17.2, RESET.P$1, S1.1, S2.1, S3.1, TP6.TP, TP9.TP, U1.GND, U1.GND1, U1.GND2, U2.3 (GND), U2.5 (GND), U2.21 (GND), U3.7 (GND), U4.7 (GND), U5.7 (GND), U6.1 (GND), U$7.GND, X1.P$1 (1), X2.P$8 (8), X3.3, X5.GND
IGNITION: X2.P$14 (14), X3.1
MIC_BIAS: C20.1, R15.2, U1.V2MICBIAS
MIC_GND: C19.1, C20.2, R16.1, X2.P$10 (10)
MIC_IN: C18.1, R15.1, X2.P$3 (3)
MIC_N: C19.2, U1.MIC_NA (MICNA)
MIC_P: C18.2, U1.MIC_NP (MICNP)
MISO: TP2.TP, U2.16 (PB4(MISO))
MODE_1: S1.2, U2.10 (PD6(AIN0))
MODE_2: S2.2, U2.11 (PD7(AIN1))
MODE_3: S3.2, U2.13 (PB1(OC1A))
MUTE_AMP: U1.GPIO9, U3.1 (CTRL), U4.1 (CTRL)
unnamed: R14.1, U1.LIN_R
unnamed: C3.2, Q1.2, U2.7 (PB6(XTAL1/TOSC1))
unnamed: C2.2, Q1.1, U2.8 (PB7(XTAL2/TOSC2))
unnamed: Q2.1 (B), R8.1
unnamed: TR2.P3 (P2), U4.8 (OUT-)
unnamed: TR2.P1, U4.5 (OUT+)
unnamed: TR3.P3 (P2), U5.8 (OUT-)
unnamed: TR3.P1, U5.5 (OUT+)
unnamed: TR1.P1, U3.5 (OUT+)
unnamed: R2.1, U3.3 (IN-)
unnamed: R3.1, U3.4 (IN+)
unnamed: R4.1, U4.3 (IN-)
unnamed: R5.1, U4.4 (IN+)
unnamed: R6.1, U5.3 (IN-)
unnamed: R7.1, U5.4 (IN+)
unnamed: C5.1, R3.2
unnamed: C4.1, R2.2
unnamed: C6.1, R4.2
unnamed: C7.1, R5.2
unnamed: C8.1, R6.2
unnamed: C9.1, R7.2
unnamed: R9.2, X1.P$4 (4)
unnamed: R10.1, X1.P$3 (3)
unnamed: R12.2, U$7.P3
unnamed: R11.2, U$7.P2
unnamed: F1.2, X3.2
unnamed: U1.USB_DP, X5.D+
unnamed: C12.2, U3.2 (BYPASS)
unnamed: C10.2, U4.2 (BYPASS)
unnamed: C11.2, U5.2 (BYPASS)
unnamed: U1.USB_DN, X5.D-
unnamed: R13.1, U1.LIN_L
unnamed: TR1.P3 (P2), U3.8 (OUT-)
unnamed: C17.1, X4.2
unnamed: C16.1, X4.5
unnamed: C17.2, R14.2
unnamed: C16.2, R13.2
unnamed: U1.GND3, X4.1
RADIO_MUTE: Q2.3 (C), X2.P$11 (11)
REMC_IN: R12.1, X2.P$7 (7)
REMC_OUT: R11.1, X2.P$15 (15)
REMOTE_IN: R10.2, U2.32 (PD2(INT0)), U$7.P4
RESET: R1.1, RESET.P$2, TP4.TP, U2.29 (PC6(/RESET))
RXD: TP7.TP, U2.30 (PD0(RXD))
TEL_AUDIO_GND: TR3.P6 (P4), X2.P$12 (12)
TEL_AUDIO_OUT: TR3.P4 (P3), X2.P$4 (4)
TEL_ENABLE: R8.2, U2.9 (PD5(T1)), U5.1 (CTRL)
TXD: TP8.TP, U2.31 (PD1(TXD))

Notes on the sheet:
Bluetooth module
Step-down 5v dc/dc converter
Audio class D amplifier
OneButtonRemote: 1 ResistaceButtonRemote: 2 SteringWheelRemote: 3
SCK
MISO
MOSI
RESET
+5V
GND
RXD
TXD
Testing pads
input/output terminal
ATmega328p module
3.3 V regulator
Microphone
Digispark module
1.1
Mute transistor
Mateusz Wróbel 2020

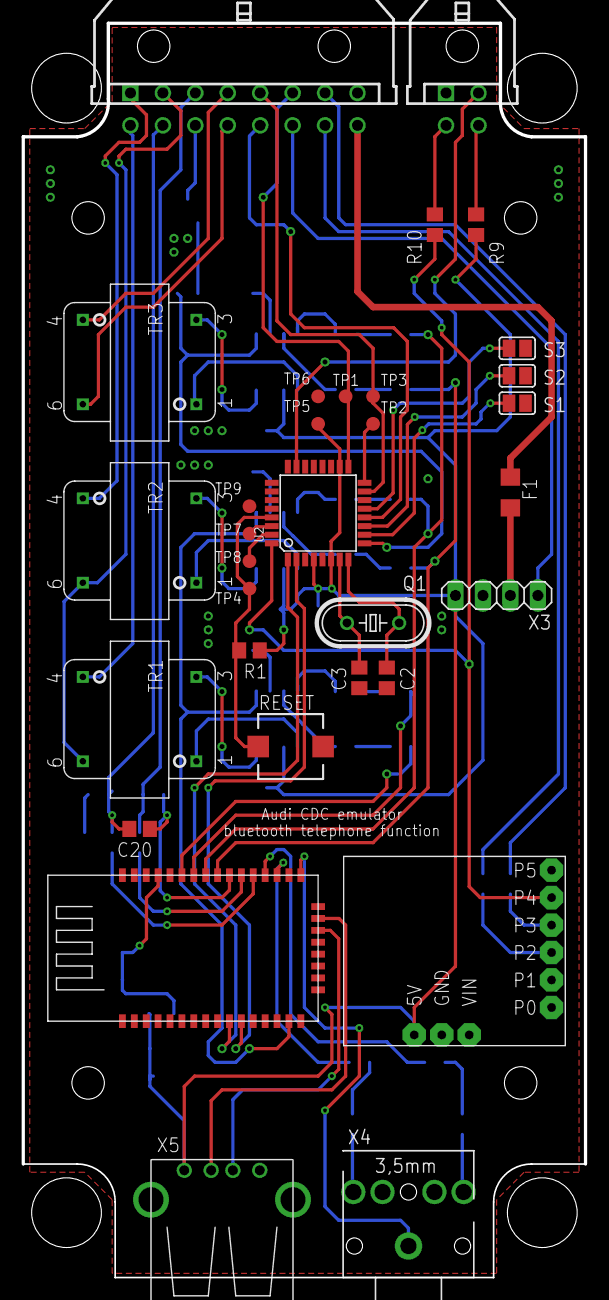
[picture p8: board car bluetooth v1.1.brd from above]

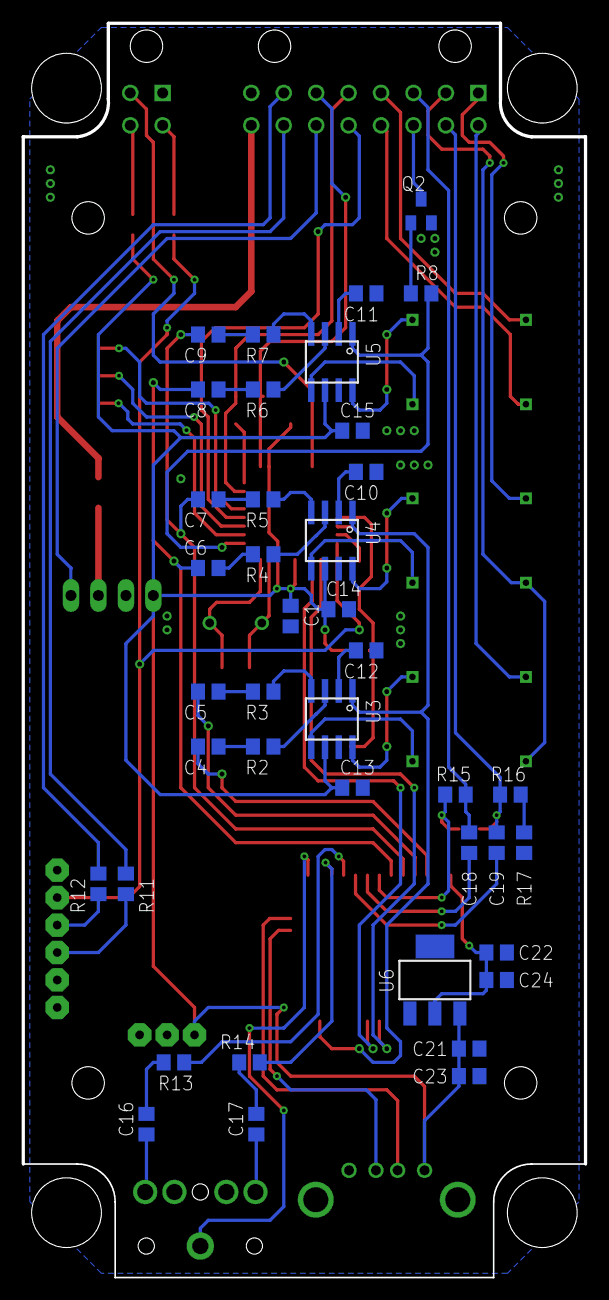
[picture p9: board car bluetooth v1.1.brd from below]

Board: 2 copper layers, 52.0 x 116.0 mm, 72 parts (40 on the bottom side), 77 nets.

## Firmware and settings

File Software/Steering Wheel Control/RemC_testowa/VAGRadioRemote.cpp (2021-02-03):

/*
  (C) Tomas Kovacik
  https://github.com/tomaskovacik/
  GNU GPL3

arduino library for V.A.G. radio remote control protocol, for reading and writing.

this library use hardcoded timer2! it is not dependant on any of it features, any timer can be used
input pin must have hardware interrupt (INTx), output pin must not be input only of corse

  Modified by Mateusz Wrobel
  v1.0 2020

====================== reading example:
#include <VAGRadioRemote.h>

#define REMOTE_PIN 2

VAGRadioRemote remote(NULL, REMOTE_PIN);

void setup() {
  remote.begin();
  //Serial.begin(115200);
}

void loop() {
 if (remote.gotNewCode()) {
    //Serial.println(remote.decodeRemote(remote.newCode()));
    remote.clearGotNewCode();
  }
}
=====================

===================== writing example on diferent device of corse
#include <VAGRadioRemote.h>

#define REMOTE_PIN 2 // this has to have hardware interrupt!

long last_update = 0;

VAGRadioRemote remote(REMOTE_PIN,NULL);


int h = 0x00;

void setup() {
  remote.begin();
  Serial.begin(115200);
}

void loop() {
  if (Serial.available() > 0)
  {
    // read the incoming byte:
    char c = Serial.read();
    switch (c)
    {
      case 'm': //mode
        remote.mode();
.
.
.
.

===================


This information is for vehicles where the radio does not use CAN bus.

## Protocol

On vehicles where the radio does not use CAN bus, the MFSW (Multifunction
Steering Wheel) controller talks to the radio using only 1 wire, which is
called `REM` (remote).

`REM` line is 5V logic, idle state is HIGH (5V)

- start bit:    9ms LOW 4.55ms HIGH
- logic 1:      ~600us LOW ~1700us HIGH
- logic 0:      ~600us LOW ~600us HIGH
- stop bit:     ~600us LOW

The MFSW controller always sends a packet of 4 bytes to the radio.  It
consists of 2 unknown header bytes, followed by a code byte, and finally
a checksum byte:

    0x41 0xE8 <code> <checksum>

The checksum is `0xFF - code`.  Example:

    0x41 0xE8 0xD0 0x2F

Code byte: `0xD0`, Checksum: `0xFF - 0xD0 = 0x2F`.

## MFSW

Using a logic analyzer, these codes were captured from an MFSW without
telephone option:

| Steering Wheel Button | Code      | Complete Packet       |
| --------------------- | --------- | --------------------- |
| UP                    | `0xD0`    | `0x41 0xE8 0xD0 0x2F` |
| DOWN                  | `0x50`    | `0x41 0xE8 0x50 0xAF` |
| LEFT                  | `0x40`    | `0x41 0xE8 0x40 0xBF` |
| RIGHT                 | `0xC0`    | `0x41 0xE8 0xC0 0x3F` |
| VOL+                  | `0x80`    | `0x41 0xE8 0x80 0x7F` |
| VOL-                  | `0x00`    | `0x41 0xE8 0x00 0xFF` |


*/

#include "VAGRadioRemote.h"
#include <Arduino.h>
#include <avr/interrupt.h>

#define USE_TIMER0
//#define USE_TIMER1
//#define USE_TIMER2


volatile static uint8_t data[2];
volatile static uint8_t sendPtr=0;// 67 is stop => 9000ms,4500ms,4x8x2 + stopbit
volatile static uint16_t counter=0;
volatile static uint8_t _outpin;
volatile static uint8_t _inpin = 3;

static volatile uint16_t captime = 0;
static volatile uint8_t captureEnabled = 0;
static volatile uint8_t capbit = 0;
static volatile uint8_t capbyte[4];
static volatile uint8_t capptr = 0;
static volatile uint8_t _gotNewCode = 0;
static volatile uint8_t _newCode = 0;

/**
   Constructor
*/

VAGRadioRemote::VAGRadioRemote(int8_t outpin,int8_t inpin)
{
if (outpin != -1){
    #define _OUTPUT
        _outpin = outpin;
    //Serial.println("Output mode");
}

if (inpin != -1){
    #define _INPUT
    _inpin = inpin;
    //Serial.println("Input mode");
}

}

/**
   Destructor
*/
VAGRadioRemote::~VAGRadioRemote(){}

#ifdef USE_TIMER0
void VAGRadioRemote::setTimer(void){
  // @ 0.5us ticks
  TCCR0A = 0x00; // Normal port operation, OC0 disconnected
  TCCR0B = 0x00; // Normal port operation, OC0 disconnected
  TCCR0A |= _BV(WGM01); // CTC mode
  TCCR0B |= _BV(CS01);// prescaler = 8 -> 1 timer clock tick is 0.5us long @ 16Mhz
  OCR0A = 49;//run compare rutine every 50us  f=20000Hz f=f_clk/(2 x prescaler x (1-OCR0A))
  TCNT0 = 0;
  TIMSK |= _BV(OCIE0A); // enable output compare interrupt A on timer0
}
#define __TIMERX_COMPA_vect TIMER0_COMPA_vect
#endif

#ifdef USE_TIMER1
void VAGRadioRemote::setTimer(void){
  // @ 0.5us ticks
  TCCR1A = 0x00; // Normal port operation, OC0 disconnected
  TCCR1B = 0x00; // Normal port operation, OC0 disconnected
  TCCR1B |= _BV(WGM12); // CTC mode
  TCCR1B |= _BV(CS11);// prescaler = 8 -> 1 timer clock tick is 0.5us long @ 16Mhz
  OCR1A = 49;//run compare rutine every 50us
  TCNT1 = 0;
  TIMSK1 |= _BV(OCIE1A); // enable output compare interrupt A on timer0
}
#define __TIMERX_COMPA_vect TIMER1_COMPA_vect
#endif

#ifdef USE_TIMER2
void VAGRadioRemote::setTimer(void){
  // @ 0.5us ticks
  TCCR2A = 0x00; // Normal port operation, OC0 disconnected
  TCCR2B = 0x00; // Normal port operation, OC0 disconnected
  TCCR2A |= _BV(WGM21); // CTC mode
  TCCR2B |= _BV(CS21);// prescaler = 8 -> 1 timer clock tick is 0.5us long @ 16Mhz
  OCR2A = 49;//run compare rutine every 50us
  TCNT2 = 0;
  TIMSK2 |= _BV(OCIE2A); // enable output compare interrupt A on timer0
}
#define __TIMERX_COMPA_vect TIMER2_COMPA_vect
#endif

void VAGRadioRemote::begin()
{

//Serial.begin(115200);

#ifdef _OUTPUT
  pinMode(_outpin,OUTPUT);
  digitalWrite(_outpin,HIGH);
  //Serial.println("output mode");
#endif

#ifdef _INPUT
  pinMode(_inpin, INPUT_PULLUP);
  attachInterrupt(digitalPinToInterrupt(_inpin), &VAGRadioRemote::remoteInGoingLow, FALLING);
  //Serial.println("input mode");
#endif
  VAGRadioRemote::setTimer();
}

ISR(__TIMERX_COMPA_vect)
{
#ifdef _INPUT

  if (captureEnabled) {
    captime++;
  }

  if (captime == 300 ) { //300x50us =>  if 15ms high pulse then reset frame
    captime = capptr = captureEnabled = 0;
    attachInterrupt(digitalPinToInterrupt(_inpin), &VAGRadioRemote::remoteInGoingLow, FALLING);
  }
#endif

#ifdef _OUTPUT
if (sendPtr>0 && counter == 0)
{
  switch (sendPtr)
  {
    case 67: //start bit, 9000us low
      digitalWrite(_outpin,LOW); //made pin LOW
      counter=372;//count form 186 to 0 for ~9000us   186
    break;
    case 66: //start bit, 4500us high
      digitalWrite(_outpin,HIGH);
      counter=174;        //87
    break;
    //regular start of bit, 600us low
    case 65:
    case 63:
    case 61:
    case 59:
    case 57:
    case 55:
    case 53:
    case 51:
    case 49:
    case 47:
    case 45:
    case 43:
    case 41:
    case 39:
    case 37:
    case 35:
          case 33:
          case 31:
          case 29:
          case 27:
          case 25:
          case 23:
          case 21:
          case 19:
          case 17:
          case 15:
    case 13:
    case 11:
    case 9:
    case 7:
    case 5:
    case 3:
    case 1:
      digitalWrite(_outpin,LOW); //made pin LOW
      counter=22; //each bit start with 600us low     //11
    break;
    //0x41 and 0xE8 data
    case 64://zeroes
    case 60:
    case 58:
    case 56:
    case 54:
    case 52:
    case 42:
    case 38:
    case 36:
    case 34:
      digitalWrite(_outpin,HIGH);
      counter=22;                     //11
    break;
    case 62://ones
    case 50:
    case 48:
    case 46:
    case 44:
    case 40:
      digitalWrite(_outpin,HIGH);
      counter=66;                     //33
    break;
    case 32:
      counter=VAGRadioRemote::bitLenght(data[0],7);
    break;
    case 30:
      counter=VAGRadioRemote::bitLenght(data[0],6);
    break;
          case 28:
                  counter=VAGRadioRemote::bitLenght(data[0],5);
          break;
    case 26:
                  counter=VAGRadioRemote::bitLenght(data[0],4);
          break;
          case 24:
                  counter=VAGRadioRemote::bitLenght(data[0],3);
          break;
          case 22:
                  counter=VAGRadioRemote::bitLenght(data[0],2);
          break;
          case 20:
                  counter=VAGRadioRemote::bitLenght(data[0],1);
          break;
          case 18:
                  counter=VAGRadioRemote::bitLenght(data[0],0);
          break;
          case 16:
                  counter=VAGRadioRemote::bitLenght(data[1],7);
          break;
          case 14:
                  counter=VAGRadioRemote::bitLenght(data[1],6);
          break;
          case 12:
                  counter=VAGRadioRemote::bitLenght(data[1],5);
          break;
          case 10:
                  counter=VAGRadioRemote::bitLenght(data[1],4);
          break;
          case 8:
                  counter=VAGRadioRemote::bitLenght(data[1],3);
          break;
          case 6:
                  counter=VAGRadioRemote::bitLenght(data[1],2);
          break;
          case 4:
                  counter=VAGRadioRemote::bitLenght(data[1],1);
          break;
          case 2:
                  counter=VAGRadioRemote::bitLenght(data[1],0);
          break;
  }
    
}
else 
{
if (counter>0)
  counter--;
if (counter == 0)
  sendPtr--;
}
if (sendPtr == 0 && counter == 0)
  digitalWrite(_outpin,HIGH); 
#endif
}

#ifdef _OUTPUT
uint8_t VAGRadioRemote::bitLenght(uint8_t _byte,uint8_t _bit){
  digitalWrite(_outpin,HIGH);
  if (!!(_byte & (1 << _bit)))
    return 66;
  else
    return 22;
}

void VAGRadioRemote::send(uint8_t _byte){ //send whole packet
  data[0]=_byte;
  data[1]=CRC(_byte);
  sendPtr=SENDPOINTERTOP;
}
#endif

#ifdef _INPUT
void VAGRadioRemote::remoteInGoingHigh() {
  captime = 0; //reset timer
  if (capptr < 4) {
    captureEnabled = 1; //we capturing only when capture pointer is less then 4th byte.
  }
  attachInterrupt(digitalPinToInterrupt(_inpin), &VAGRadioRemote::remoteInGoingLow, FALLING);
}

void VAGRadioRemote::remoteInGoingLow() {
  if (captureEnabled) {
    //we have ticked in some data, lets calculate what we capture
    captureEnabled = 0; //disable future counting in timer2
    if (captime > 89) {//start bit 4.55ms 89x50us=4450

      capbit = capptr = 0; //start of packet, lets reset it all to begining
      capbyte[0] = capbyte[1] = capbyte[2] = capbyte[3] = 0;

    } else {

      if (captime > 10) { //logic 0 is 600us pulse, 50x10=500us
        capbyte[capptr] <<= 1;
      }
      if (captime > 32) { //32*50us , more then 1600us
        capbyte[capptr] |= 1;
      }
      capbit++;

    }

    if (capbit == 8) { //we got whole byte, lets
      capptr++;
      capbit = 0;
    }

    if (capptr == 4) {  //let's print what we got
      //Serial.print(capbyte[0],HEX);
      //Serial.print(" ");
      //Serial.print(capbyte[1],HEX);
      //Serial.print(" ");
      //Serial.print(capbyte[2],HEX);
      //Serial.print(" ");
      //Serial.println(capbyte[3],HEX);
    
      if (capbyte[0] == 0x41 && capbyte[1] == 0xE8 && capbyte[3] == 0xFF - capbyte[2]) {
        _newCode = capbyte[2];
        _gotNewCode = 1;
        capptr = 0;
      }
    
    else {  //if frames are wrong, reset all data
    //Serial.println("Frames error");
        capbit = capptr = 0; //start of packet, lets reset it all to begining
        capbyte[0] = capbyte[1] = capbyte[2] = capbyte[3] = 0;
      }
    }

  }
  attachInterrupt(digitalPinToInterrupt(_inpin), &VAGRadioRemote::remoteInGoingHigh, RISING);
}

String VAGRadioRemote::decodeRemote(uint8_t code) {
  /*
    UP:     0x41E8D02F
    DOWN:   0x41E850AF
    LEFT:   0x41E840BF
    RIGHT:  0x41E8C03F
    VOL+:   0x41E8807F
    VOL-:   0x41E800FF
  */
  switch (code) {
    case VOLUMEDOWN: return F("Volume down");
    case BTN1: return F("mem/cd1");
    case BTN2: return F("mem/cd2");//Did not work on my audi concert ...
    case BTN3: return F("mem/cd3");
    case BTN4: return F("mem/cd4");//Did not work on my audi concert ...
    case BTN5: return F("mem/cd5");
    case BTN6: return F("mem/cd6");//Did not work on my audi concert ...
    case REG: return F("radio regional on/off");
    case AM: return F("AM");
    case AS: return F("AS-STORE");
    case FM: return F("FM");
    case RANDOM: return F("random");
    case LEFT:
    case 0x42:
    case 0x44:
    case 0x46: return F("LEFT FM1 6-5-4-3-2-1-FM2 6-5-4-3-2-1");
    case DOWN:
    case 0x52:
    case 0x54:
    case 0x56:
    case 0x60:
    case 0x62:
    case 0x64: return F("Seek down/FR");
    case VOLUMEUP:
    case 0x81:
    case 0x82:
    case 0x83:
    case 0x84:
    case 0x85:
    case 0x86: return F("Volume up");
    case DOWN_2: return F("-2 Volume down bas/treble down/fade rear/bal left");
    case DOWN_4: return F("-4 Volume down bas/treble down/fade rear/bal left");
    case DOWN_6: return F("-6 Volume down bas/treble down/fade rear/bal left");
    case DOWN_8: return F("-8 Volume down/fade rear/bal left");
    case TP: return F("TP");
    case SCAN: return F("SCAN");
    case MODE:
    case 0xA2:
    case 0xA4:
    case 0xA6: return F("MODE");
    case RIGHT:
    case 0xC2:
    case 0xC4:
    case 0xC6: return F("RIGHT FM1 6-5-4-3-2-1-FM2 6-5-4-3-2-1");
    case UP:
    case 0x07: return F("Seek up/FF");
  }
  return "unknown";
}

String VAGRadioRemote::decodeRemote(){
  return decodeRemote(_newCode);
}

uint8_t VAGRadioRemote::gotNewCode(){
  return _gotNewCode;
}

uint8_t VAGRadioRemote::newCode(){
  return _newCode;
}

void VAGRadioRemote::clearGotNewCode(){
  _gotNewCode=0;
}
#endif

#ifdef _OUTPUT
void VAGRadioRemote::up(){
  VAGRadioRemote::send(UP);
}

void VAGRadioRemote::cdUp(){
        VAGRadioRemote::send(CDUP);
}


void VAGRadioRemote::down(){
  VAGRadioRemote::send(DOWN);
}

void VAGRadioRemote::cdDown(){
        VAGRadioRemote::send(CDDOWN);
}


void VAGRadioRemote::left(){
  VAGRadioRemote::send(LEFT);
}

void VAGRadioRemote::right(){
  VAGRadioRemote::send(RIGHT);
}

void VAGRadioRemote::volumeUp(){
        VAGRadioRemote::send(VOLUMEUP);
}

void VAGRadioRemote::volumeDown(){
        VAGRadioRemote::send(VOLUMEDOWN);
}

void VAGRadioRemote::button(uint8_t buttonNumber){
  VAGRadioRemote::send(buttonNumber);
}

void VAGRadioRemote::reg(){
        VAGRadioRemote::send(REG);
}

void VAGRadioRemote::am(){
        VAGRadioRemote::send(AM);
}

void VAGRadioRemote::as(){
        VAGRadioRemote::send(AS);
}

void VAGRadioRemote::fm(){
        VAGRadioRemote::send(FM);
}

void VAGRadioRemote::random(){
        VAGRadioRemote::send(RANDOM);
}

void VAGRadioRemote::tp(){
  VAGRadioRemote::send(TP);
}

void VAGRadioRemote::scan(){
  VAGRadioRemote::send(SCAN);
}

void VAGRadioRemote::mode(){
  VAGRadioRemote::send(MODE);
}
#endif

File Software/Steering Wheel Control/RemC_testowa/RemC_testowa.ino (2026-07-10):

/* 
audi steering wheel decoder

ported for : attiny 85 (digispark) 16MHz
*/

#include "VAGRadioRemote.h"
#include <SoftwareSerial.h>


#define REMOTE_OUT 0
#define REMOTE_IN 2
#define COMUNICATION_PIN 4
#define SERIAL_TX_PIN 1
#define LONGPRESS_COUNT 20

SoftwareSerial mySerial(0, SERIAL_TX_PIN); // RX, TX
VAGRadioRemote remote(REMOTE_OUT, REMOTE_IN);

uint8_t phoneCounter = 0;
 
void setup() {
  mySerial.begin(9600);
  mySerial.println("Steering wheel decoder");
  remote.begin();
  pinMode(REMOTE_OUT,OUTPUT);
  //digitalWrite(COMUNICATION_PIN,LOW);
  mySerial.println("setup finish");
}

void loop() {
  if (remote.gotNewCode()) {
    if(remote.newCode()==0x40)  { //if R/T button code
      remote.send(0xA0);  //change mode 0xA0
    }
    else if(remote.newCode()==0xC0) { //if phone button code
      phoneCounter++;
      if(phoneCounter >= LONGPRESS_COUNT) {  //longpress detection
        mySerial.print("phone longpress\n");
        phoneCounter = 0;
      }
      else {
        mySerial.print("phone press\n");
      }
      
    }
    else {  //if other button send normal comand
      remote.send(remote.newCode());
    }
    remote.clearGotNewCode();
  }    
}

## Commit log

2021-02-03 start repo
    [car bluetooth v1.1.brd, car bluetooth v1.1.sch]
2023-01-29 Porządki w kodzie
    utworzone klasy
    [charakterystyka modul bt.xlsx, lista części audi bt.xlsx]
2026-07-10 Clean old version of files, add new code for Atmega328PB
    [car bluetooth v1.1.brd]
2026-07-10 Clean old files, add support for Atmega328PB
    [BM83_breadboard_adapter.kicad_pcb, BM83_breadboard_adapter.kicad_sch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]
